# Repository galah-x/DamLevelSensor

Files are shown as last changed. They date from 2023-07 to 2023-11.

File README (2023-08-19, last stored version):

A water level monitor was made to monitor a farm dam level, it seems we may be moving into another drought.

Its an ultrasonic sensor to measure the distance from a fixed mount above the water, pointing down, and a arduino + LoRa radio for the datalink to the logging computer in the office. Solar powered.

The structure I live in is timber with corrugated iron for roof and wall sheeting. Thats not good for radios. So there is a radio relay on the roof relaying both RFM69 and RFM95 radio links into the office. This also provides some lightning protection.

The dam is about 0.5km from the house, LoRa can do that easily even from inside the slightly conductive black poly pipe.

Another USB motino with a radio link presents data to a linux computer, which logs the serial data and stores it in an influx database. Grafana on an internal http server then presents data to the user nicely. I don't currently use MQTT or LoRaWan.

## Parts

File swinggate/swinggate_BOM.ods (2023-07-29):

Id | Designator | Package | Quantity | Designation | Supplier and ref
1 | U3 | IBT_2 | 1 | IBT2_HBRIDGE | https://www.ebay.com.au/itm/Semiconductor-Motor-Driver-Auto-BTS7960-43A-H-Bridge-PWM-Drive-For-Arduino-U1C6-/302749142576
3 | C1,C2,C3,C4,C5 | C_0805_2012Metric_Pad1.15x1.40mm_HandSolder | 5 | 100N
4 | D1 | D_SMA-SMB_Universal_Handsoldering | 1 | APD240VR
5 | J1,J3,J4,J5 | PhoenixContact_MC_1,5_2-G-5.08_1x02_P5.08mm_Horizontal | 4 | Conn_01x02_Female | https://www.ebay.com.au/itm/10pcs-5-08mm-2-EDG-2-Pin-Plug-in-Right-Angle-PCB-Screw-Terminal-Block-Connector/292835245321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
6 | Q1 | TO-263-3_TabPin2 | 1 | IPB081
7 | R3 | R_0805_2012Metric_Pad1.15x1.40mm_HandSolder | 1 | 402K
8 | R4,R9,R10,R11,R13,R15 | R_0805_2012Metric_Pad1.15x1.40mm_HandSolder | 6 | 100K
9 | R5,R6 | R_0805_2012Metric_Pad1.15x1.40mm_HandSolder | 2 | 10K
10 | R7,R8 | R_0805_2012Metric_Pad1.15x1.40mm_HandSolder | 2 | 1K2
11 | R12,R14,R16 | R_0805_2012Metric_Pad1.15x1.40mm_HandSolder | 3 | 33K
12 | U1 | switcher1 | 1 | switcher1 | https://www.ebay.com.au/itm/DC-DC-9V-12V-19V-To-3A-5V-3-3V-USB-Step-Down-Buck-Power-Supply-Module-For-Car/282743651974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
13 | U2 | DIP-26_W0.8_Socket | 1 | Moteino_hcw | https://lowpowerlab.com/shop/product/99
14 | J2 | PhoenixContact_MC_1,5_4-G-5.08_1x04_P5.08mm_Horizontal | 1 | Conn_01x04_Female | https://www.ebay.com.au/itm/9Pairs-4Pole-5-08mm-Plug-Type-Pitch-PCB-Mount-with-Right-Angle-Pin-B9U1/273040528477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
 | additional mechanical
 |  | threaded standoff 25mm m3 | 4 | for U3 | https://www.ebay.com.au/itm/100pcs-M3-5-25mm-Black-PA66-Nylon-Hexagon-Female-Threaded-Standoff-Spacer-Pillar/182482464251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
 |  | 8 pin header | 1 | for U3
 |  | ribbon cable 8 pin idc socket | 2 | for U3 | https://www.ebay.com.au/itm/2-54mm-FC-6-51-Way-IDC-Female-Flat-Ribbon-Cable-Mounting-Socket-Connector-Kit/222895237965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
 |  | ribbon cable 50mm | 1 | for U3
 |  | m3 machine screw 6mm | 8 | for U3 | https://www.ebay.com.au/itm/M3x10mm-316-Stainless-Steel-Phillips-Round-Pan-Head-Machine-Screw-Bolt-60pcs/352046660471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
 |  | pin strip x 13 mc screw female | 2 | for U2 | https://www.ebay.com.au/itm/2-10x-Strip-Tin-PCB-Female-IC-Breakable-40pin-Single-Row-Round-Header-Socket/161925149885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
 |  | pin strip x 13 mc screw male | 2 | for U2 | https://www.ebay.com.au/itm/20pcs-40Pin-2-54mm-Male-Female-Header-Socket-Row-Straight-Strip-PCB-Connector/152053905428

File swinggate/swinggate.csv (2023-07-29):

Id | Designator | Package | Quantity | Designation | Supplier and ref
1 | U3 | IBT_2 | 1 | IBT2_HBRIDGE
2 | H1,H2,H3 | MountingHole_3.2mm_M3_DIN965_Pad | 3 | MountingHole
3 | C1,C2,C3,C4,C5 | C_0805_2012Metric_Pad1.15x1.40mm_HandSolder | 5 | 100N
4 | D1 | D_SMA-SMB_Universal_Handsoldering | 1 | APD240VR
5 | J1,J3,J4,J5 | PhoenixContact_MC_1,5_2-G-5.08_1x02_P5.08mm_Horizontal | 4 | Conn_01x02_Female
6 | Q1 | TO-263-3_TabPin2 | 1 | IPB081
7 | R3 | R_0805_2012Metric_Pad1.15x1.40mm_HandSolder | 1 | 402K
8 | R4,R9,R10,R11,R13,R15 | R_0805_2012Metric_Pad1.15x1.40mm_HandSolder | 6 | 100K
9 | R5,R6 | R_0805_2012Metric_Pad1.15x1.40mm_HandSolder | 2 | 10K
10 | R7,R8 | R_0805_2012Metric_Pad1.15x1.40mm_HandSolder | 2 | 1K2
11 | R12,R14,R16 | R_0805_2012Metric_Pad1.15x1.40mm_HandSolder | 3 | 33K
12 | U1 | switcher1 | 1 | switcher1
13 | U2 | DIP-26_W0.8_Socket | 1 | Moteino_hcw
14 | J2 | PhoenixContact_MC_1,5_4-G-5.08_1x04_P5.08mm_Horizontal | 1 | Conn_01x04_Female

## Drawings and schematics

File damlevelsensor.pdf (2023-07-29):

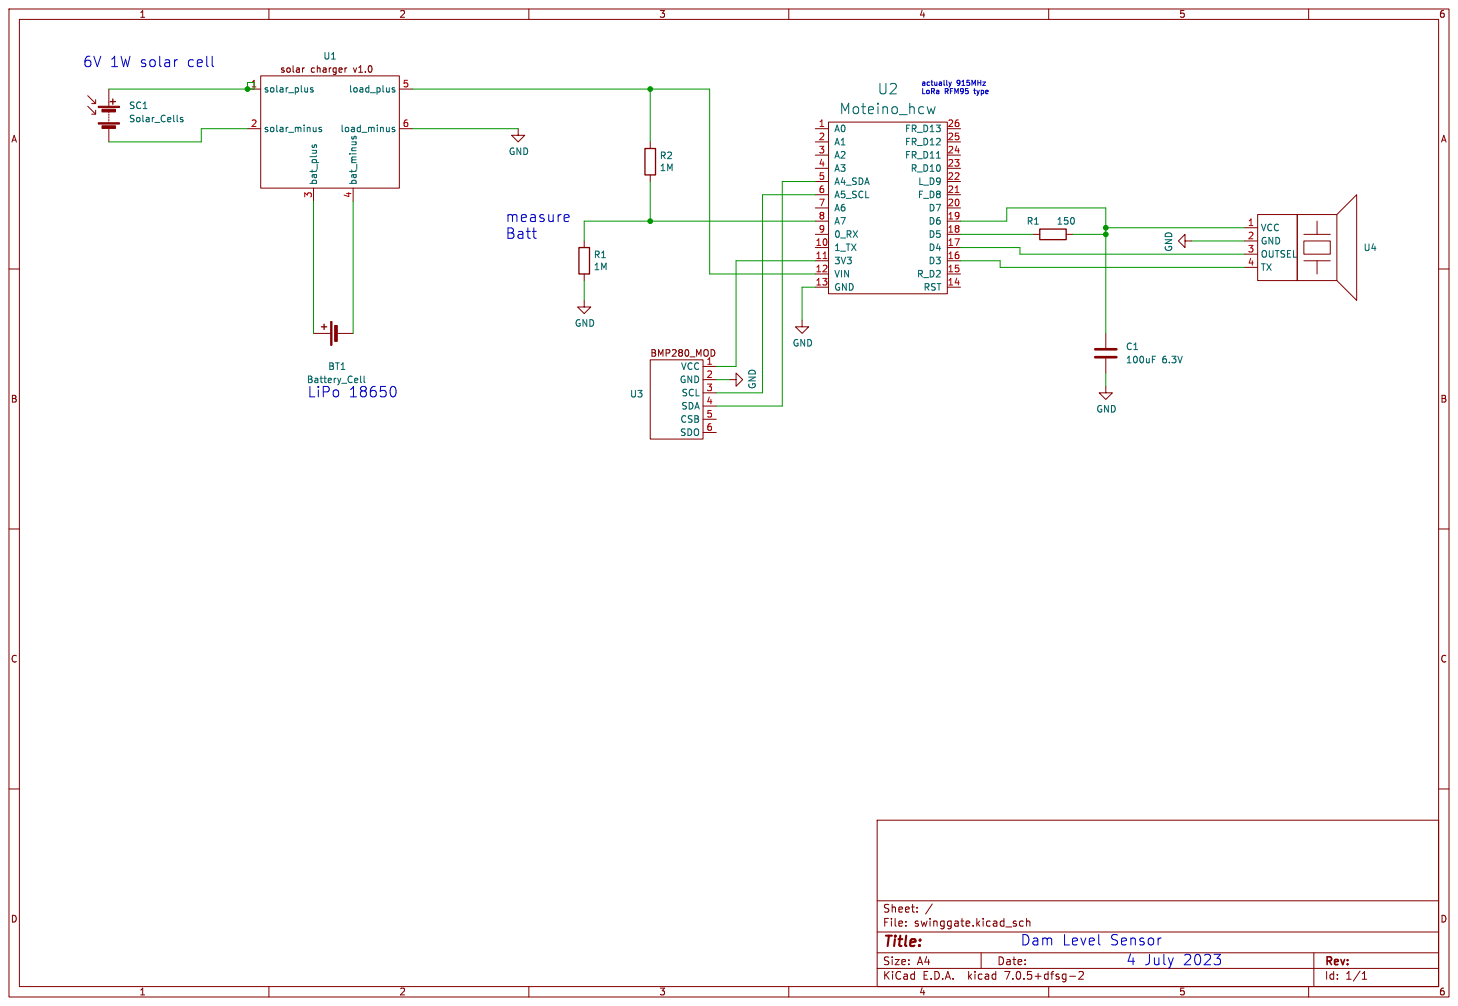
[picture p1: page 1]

Id: 1/1 Title: File: swinggate.kicad_sch Sheet: /

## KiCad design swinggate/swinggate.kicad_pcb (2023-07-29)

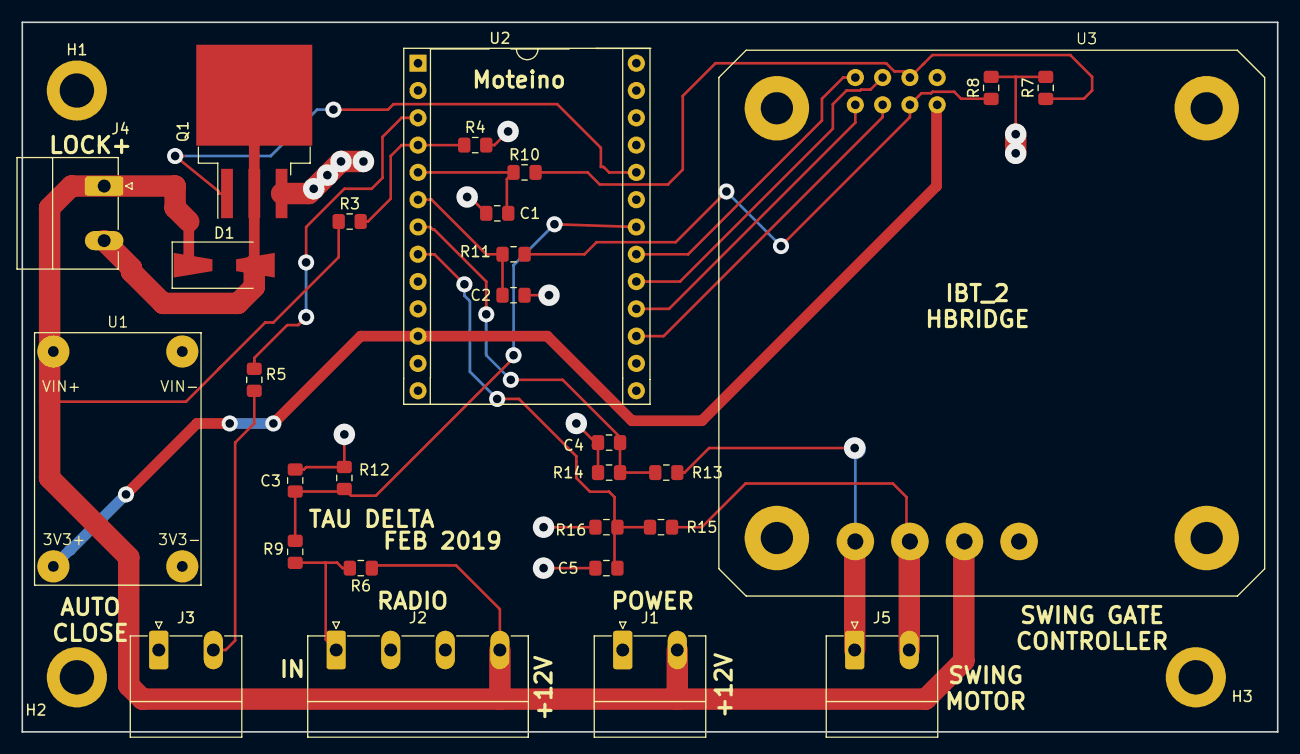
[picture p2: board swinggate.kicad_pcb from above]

Board: 2 copper layers, 116.8 x 66.0 mm, 32 parts (0 on the bottom side), 22 nets.

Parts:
C1, C2, C3, C4, C5: 100N; C_0805_2012Metric_Pad1.15x1.40mm_HandSolder
D1: APD240VR; D_SMA-SMB_Universal_Handsoldering
H1, H2, H3: MountingHole; MountingHole_3.2mm_M3_DIN965_Pad
J1, J3, J4, J5: Conn_01x02_Female; PhoenixContact_MC_1,5_2-G-5.08_1x02_P5.08mm_Horizontal
J2: Conn_01x04_Female; PhoenixContact_MC_1,5_4-G-5.08_1x04_P5.08mm_Horizontal
Q1: IPB081; TO-263-3_TabPin2
R3: 402K; R_0805_2012Metric_Pad1.15x1.40mm_HandSolder
R4, R9, R10, R11, R13, R15: 100K; R_0805_2012Metric_Pad1.15x1.40mm_HandSolder
R5, R6: 10K; R_0805_2012Metric_Pad1.15x1.40mm_HandSolder
R7, R8: 1K2; R_0805_2012Metric_Pad1.15x1.40mm_HandSolder
R12, R14, R16: 33K; R_0805_2012Metric_Pad1.15x1.40mm_HandSolder
U1: switcher1
U2: Moteino_hcw; DIP-26_W0.8_Socket
U3: IBT2_HBRIDGE; IBT_2

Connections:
+3V3: U1.2, U2.11, U3.7
+12V: D1.1, J1.2, J2.4, J4.1, R3.1, R6.1, U1.1, U3.11
/AUTOCLOSE: R5.1, U2.3
/BATTV_FB: R3.2, R4.1, U2.4
/DRN_L: U2.19, U3.2
/DRN_R: U2.17, U3.1
/IM_FB_L: C1.1, R10.1, U2.5
/IM_FB_R: C2.1, R11.1, U2.6
/IM_L: R7.1, R10.2, U3.6
/IM_R: R8.1, R11.2, U3.5
/ML: J5.1, R13.1, U3.9
/ML_BEMF_FB: C4.1, R13.2, R14.1, U2.7
/MR: J5.2, R15.1, U3.10
/MR_BEMF_FB: C5.1, R15.2, R16.1, U2.8
/PWM_L: U2.18, U3.4
/PWM_R: U2.16, U3.3
/START_N: J2.1, R6.2, R9.2
/START_N_FB: C3.1, R9.1, R12.1, U2.20
/UNLOCK: Q1.1, U2.22
/UNLOCK_N: D1.2, J4.2, Q1.2
GND: C1.2, C2.2, C3.2, C4.2, C5.2, J1.1, J2.2, J2.3, J3.1, Q1.3, R4.2, R7.2, R8.2, R12.2, R14.2, R16.2, U1.3, U1.4, U2.13, U3.8, U3.12
unnamed: J3.2, R5.2

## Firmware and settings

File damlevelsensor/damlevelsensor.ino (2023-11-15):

//    -*- Mode: c++     -*-
// emacs automagically updates the timestamp field on save
// my $ver =  'dam sonar level sensor  Time-stamp: "2023-09-01 12:00:02 john"';

// Im currently using arduino-1.8.10 as thats where some of the libraries are installed.
// for a moteino 328P with LoRa radio,  no USB. no flash.

#include <RHReliableDatagram.h>
#include <RH_RF95.h>         // last 2 for the NRF95 LoRa module 
#include <Wire.h>
#include <Adafruit_Sensor.h>
#include <Adafruit_BMP280.h> // last 3 for the temp sensor
#include <avr/wdt.h>         // watchdog
#include <LowPower.h>        // sleep mode
#include <SoftwareSerial.h>  // for the Sonar module
#include "pinout.h"          // IO pin map
#include "addresses.h"       // radio addresses
#include "cal.h"             // adc + resistor cal values
// #include "functions.h"  is placed _after_ the local variable defines

// the F() macro puts strings into flash, not RAM.
// Lighter on RAM which on a 328P is usually more limiting
#define fVERSION  F("20230901")
#define fIAM      F("DamLevel")
#define fTEMP     F("Temp=")

// onboard HW serial is used for DEBUG. Should NOT be defined for normal operation
// this is to the programmer connector.   The  arduino  Serial. object. 
// this #define does NOT affect SoftwareSerial to the Sonar module.
// #define DOSERIAL
#define SERIAL_BAUD 115200

// The radio IS used for normal operation. Generally turn radio on and serial off
// for normal installed use.
// Mainly controllable here since LoRa in my office affects the link to relay, LogRX,
// poorly. So I do most initial runup on serial debug.
#define DORADIO

// allow 3000ms (3S) for a sonar measurement. I saw just over 1s.
// And pat the dog while waiting for the averaged ping.
#define SONAR_TIMEOUT 3000
#define SONAR_PAT 1

Adafruit_BMP280 tempsensor;    // I2C temperature sensor is a bmp280
float temperature;
float batt_v;

// The moteino only has one hw serial port, which is used for debug.
// Im going to use SW serial for the Sonar sensor, as
// (1) its slow at 9600 baud.
// (2) I know when its supposed to be on.
// (3) its RX only, all suiting the pin interrupt, half duplex SW model
// However, as the SW serial doesn't (appear to) support a queue empty when only
// one port exists, and as a powerdown of the sonar looks a lot like a start bit, I'll
// create a second imaginary serial port to switch to and from.
SoftwareSerial SonarComms (FROM_SONAR_TX, TO_SONAR_DUMMY_RX);
SoftwareSerial UnusedComms (SECOND_SWSERIAL_RX, TO_SONAR_DUMMY_RX);

// Singleton instance of the radio driver
RH_RF95 radio;

// Class to manage message delivery and receipt, using the radio driver declared above
RHReliableDatagram Rmanager(radio, NODEID);


const uint8_t SHORT_RH_RF95_MAX_MESSAGE_LEN = 50;
uint8_t buf[SHORT_RH_RF95_MAX_MESSAGE_LEN+1];
char bufnum[8];    // want to allow -ddd.dd<null>
char bufnum2[8];

uint8_t loopcounter_2secs ; 
uint8_t loopcounter_mins ; 
uint8_t loopcounter_hours ; 

// functions.h needs the odd global variable, so its down here.
#include "functions.h"     // various named functions


void setup()
{
#ifdef DOSERIAL
  Serial.begin(SERIAL_BAUD);
  snprintf_P(buf, sizeof(buf), PSTR("0x%x %S %S"), NODEID, fIAM, fVERSION);
  Serial.println((char *)buf);
  Serial.flush();
#endif

  digitalWrite(SONAR_OUTSEL, 0);       //  average/processed not instantaneous
  // I played with this, 0 seemed a little slower + better filtered.
  
  digitalWrite(SONAR_PRECHARGE,0);     //  power off.
  digitalWrite(SONAR_POWER, 0);        //  power off.
  digitalWrite(TO_SONAR_DUMMY_RX, 0);  //  imaginary output pin for SWserial
  pinMode(FROM_SONAR_TX, INPUT);       // SWSerial input
  pinMode(SECOND_SWSERIAL_RX, INPUT_PULLUP); // imaginary second SWSERIAL input
  pinMode(TO_SONAR_DUMMY_RX, OUTPUT);  // imaginary SWSerial output
  pinMode(SONAR_OUTSEL,  OUTPUT);      // Sonar filtering control
  pinMode(SONAR_PRECHARGE,  OUTPUT);   // Sonar power 
  pinMode(SONAR_POWER,  OUTPUT);       // main Sonar power 
  pinMode(BATT_ADC, INPUT);            // battery voltage monitor
  
  power_sonar(0);
  SonarComms.begin(9600);
  UnusedComms.begin(9600);
  UnusedComms.listen();      // switch SWSerial to a high unused input
  
  // now blink the led a couple of times to show booting visually
  pinMode(LED, OUTPUT);
  delay(1000);
  Blink(LED, 100);
  delay (100);
  Blink(LED, 100);
  delay (100);
  
  loopcounter_2secs = 0; 
  loopcounter_mins = 0 ; 
  loopcounter_hours = 0 ; 
   
#ifdef DORADIO
#ifdef DOSERIAL      // note these serial calls are nested inside the DORADIO enable
  Serial.println(F("now init radio"));
  Serial.flush();
#endif
  
  // initialize the radio if it should be enabled
  if (!Rmanager.init()) {
    while (1) {  // radio broken, just blink fast.
      Blink(LED, 100);
      delay (100);
    }
  }
  radio.setFrequency(915);    // to be sure, to be sure
  radio.setModemConfig(RH_RF95::Bw31_25Cr48Sf512);  //set for pre-configured slow,long range
  radio.setTxPower(20);       //set for 100mw , +20dbm
  
#ifdef DOSERIAL
  Serial.println(F("done init radio"));
  Serial.flush();
#endif
#endif   // end of DORADIO switch

  // now initialize the temperature sensor 
  if (!tempsensor.begin(0x76))  // ebay module is at address 0x76 not (adafruit) 0x77
    {
      while (1) {  // temp sensor is broken, just blink med fast.
        Blink(LED, 200);
        delay (200);
      }
    }

  wdt_enable(WDTO_8S);
  wdt_reset();
  
  delay (1000);

#ifdef DOSERIAL
  Serial.println("hi");   // needed for the next bit to execute. No Idea why!
  Serial.flush();
#endif
  
#ifdef DOSERIAL
  dtostrf((BATT_GAIN * analogRead(BATT_ADC)), 5, 2, bufnum);
  dtostrf(tempsensor.readTemperature(),  5, 2, bufnum2);
  snprintf_P((char *)buf, sizeof(buf), PSTR("V=%s T=%s°C D=%dmm"), bufnum, bufnum2, sonar_depth(SONAR_TIMEOUT, SONAR_PAT));  
  Serial.println((char *)buf);
  Serial.flush();
#endif

  
#ifdef DORADIO
  snprintf_P(buf, sizeof(buf), PSTR("%c%c%S %S"), LOGGER, NODEID, fIAM, fVERSION);
  sendMsg(RELAY);
#endif


#ifdef DOSERIAL
  Serial.println(F("done setup"));
  Serial.flush();
#endif
}

void loop(void)
{
  int16_t depth;
  loopcounter_2secs++ ;
  if (loopcounter_2secs > 29)  // 1 minute
    {
      loopcounter_2secs=0;
      loopcounter_mins++;
    }
  if (loopcounter_mins > 59)
    {
      loopcounter_mins=0;
      loopcounter_hours++;
    }
  // repeated action after a desired interval 
  if ((loopcounter_hours == 2) &&
      (loopcounter_mins == 0) &&
      (loopcounter_2secs == 0))
    {
      loopcounter_hours = 0;
      loopcounter_mins = 0;
      loopcounter_2secs = 0;
      
#ifdef DOSERIAL
      dtostrf((BATT_GAIN * analogRead(BATT_ADC)), 5, 2, bufnum);
      dtostrf(tempsensor.readTemperature(),  5, 2, bufnum2);
      snprintf_P((char*) buf, sizeof(buf), PSTR("V=%s T=%s°C D=%dmm"), bufnum,bufnum2, sonar_depth(SONAR_TIMEOUT, SONAR_PAT));  
      Serial.println((char *)buf);
      Serial.flush();
#endif

#ifdef DORADIO
      radio_print_VTD(SONAR_TIMEOUT, SONAR_PAT);
#endif
    }
  LowPower.powerDown(SLEEP_2S, ADC_OFF, BOD_OFF);
  wdt_reset();    // pat the dog
}

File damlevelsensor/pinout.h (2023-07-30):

//    -*- Mode: c++     -*-
// emacs automagically updates the timestamp field on save
// my $ver =  'dam sonar level sensor pinout Time-stamp: "2023-07-30 11:02:10 john"';

// basic moteino uses the atmega328
const byte LED                = 9;  // Moteino onboard LED is on D9

// and these are the IOs used for the Dam level Sensor Sonar Lora

const byte FROM_SONAR_TX      = 3;  // input for sonar tx transmission
const byte TO_SONAR_DUMMY_RX  = 7;  // sonar tx transmission
const byte SECOND_SWSERIAL_RX = 8;  // switch SW serial to this when SONAR is off. 
const byte SONAR_OUTSEL       = 4;  // OUTSEL , controls averaging
const byte SONAR_PRECHARGE    = 5;  // Sonar Vdd via current limit resistor
const byte SONAR_POWER        = 6;  // Sonar VDD, controls averaging, with 100uf cap.
const byte BATT_ADC           = A7;  // analog IO for measuring battery

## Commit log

2023-07-29 initial commit, runiing temp+depth to serial debug
    [dls.kicad_pcb, dls.kicad_sch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]
2023-07-29 added serial voltage mon. Now reporting hourly , will run overnight to ceiling to look for thermal effects
2023-07-30 improve commenting a bit, and look for temperature sensitivity in overnight run
2023-07-30 fix bug in D= printing
    [damlevelsensor.ino, functions.h]
